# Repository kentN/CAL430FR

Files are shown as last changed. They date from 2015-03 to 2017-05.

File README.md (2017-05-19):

# CAL.430FR #

MSP430FR5949 TimeKeeping Module with ADXL362 & Sharp MemoryLCD



----------

## Features ##

- MSP430FR5949 FRAM MCU (FRAM 64kB, SRAM 2kB, LFXT only)
- Sharp Memory LCD (128x128pixcel or 96x96pixcel)
- 5 button
- Low Power Accelerometer ADXL362
- 32.768kHz External Crystal
- CR2032 Coin Cell battery (Diode OR option)
- External Connector(DF12-20p) includes MSP430 prog pin, UART(x2ch), SPI(x1), GPIO(x9)

----------
## Applications ##

- DIY WristWatch
- Embedded Display&TimeKeeping module
- Motion Data Logger

----------

## Project Environment ##

- KiCad (4.0.1)
- MSP430FR5969 LaunchPad
- Energia IDE
- CCSv6

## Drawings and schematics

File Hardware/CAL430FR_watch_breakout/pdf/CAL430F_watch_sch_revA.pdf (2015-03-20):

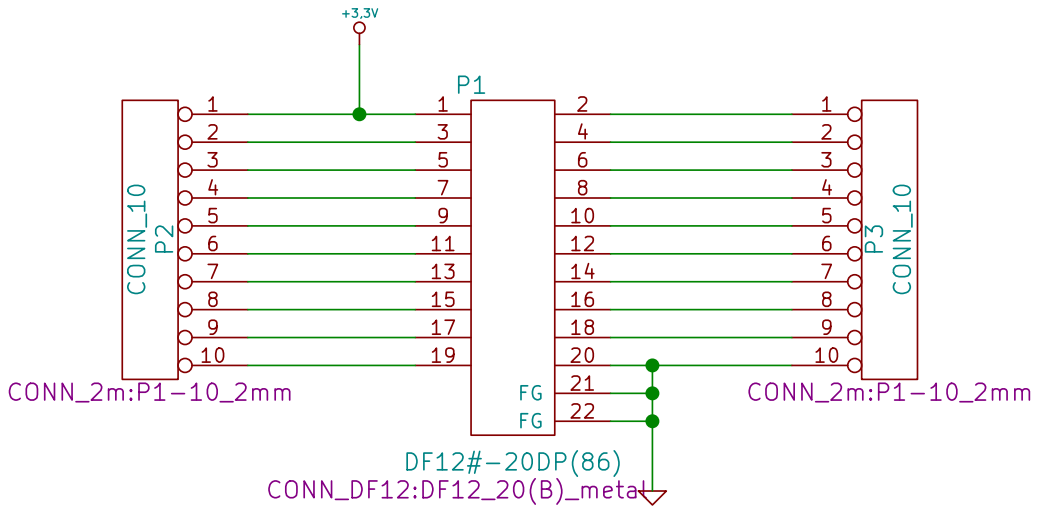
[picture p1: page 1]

File: CAL430F_PROG.sch Sheet: / Kent Nakazawa (kent_n@outlook.com)

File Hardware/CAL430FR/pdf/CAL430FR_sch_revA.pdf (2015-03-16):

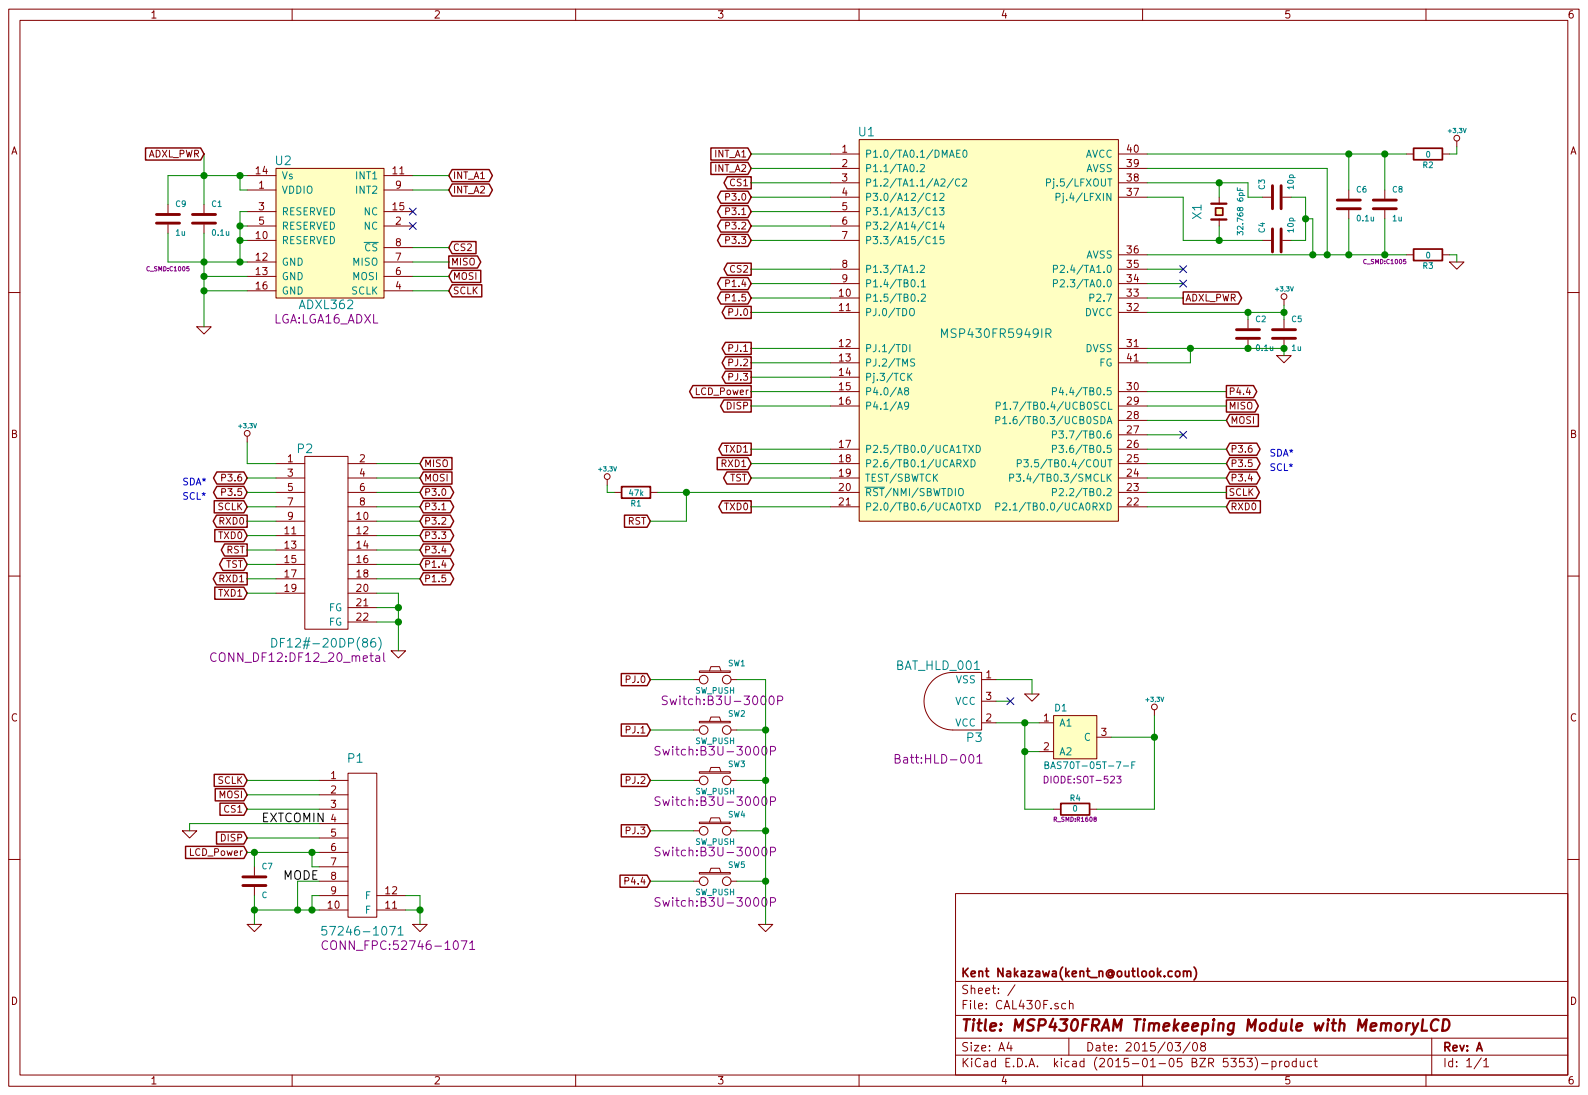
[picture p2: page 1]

Id: 1/1 Title: MSP430FRAM Timekeeping Module with MemoryLCD

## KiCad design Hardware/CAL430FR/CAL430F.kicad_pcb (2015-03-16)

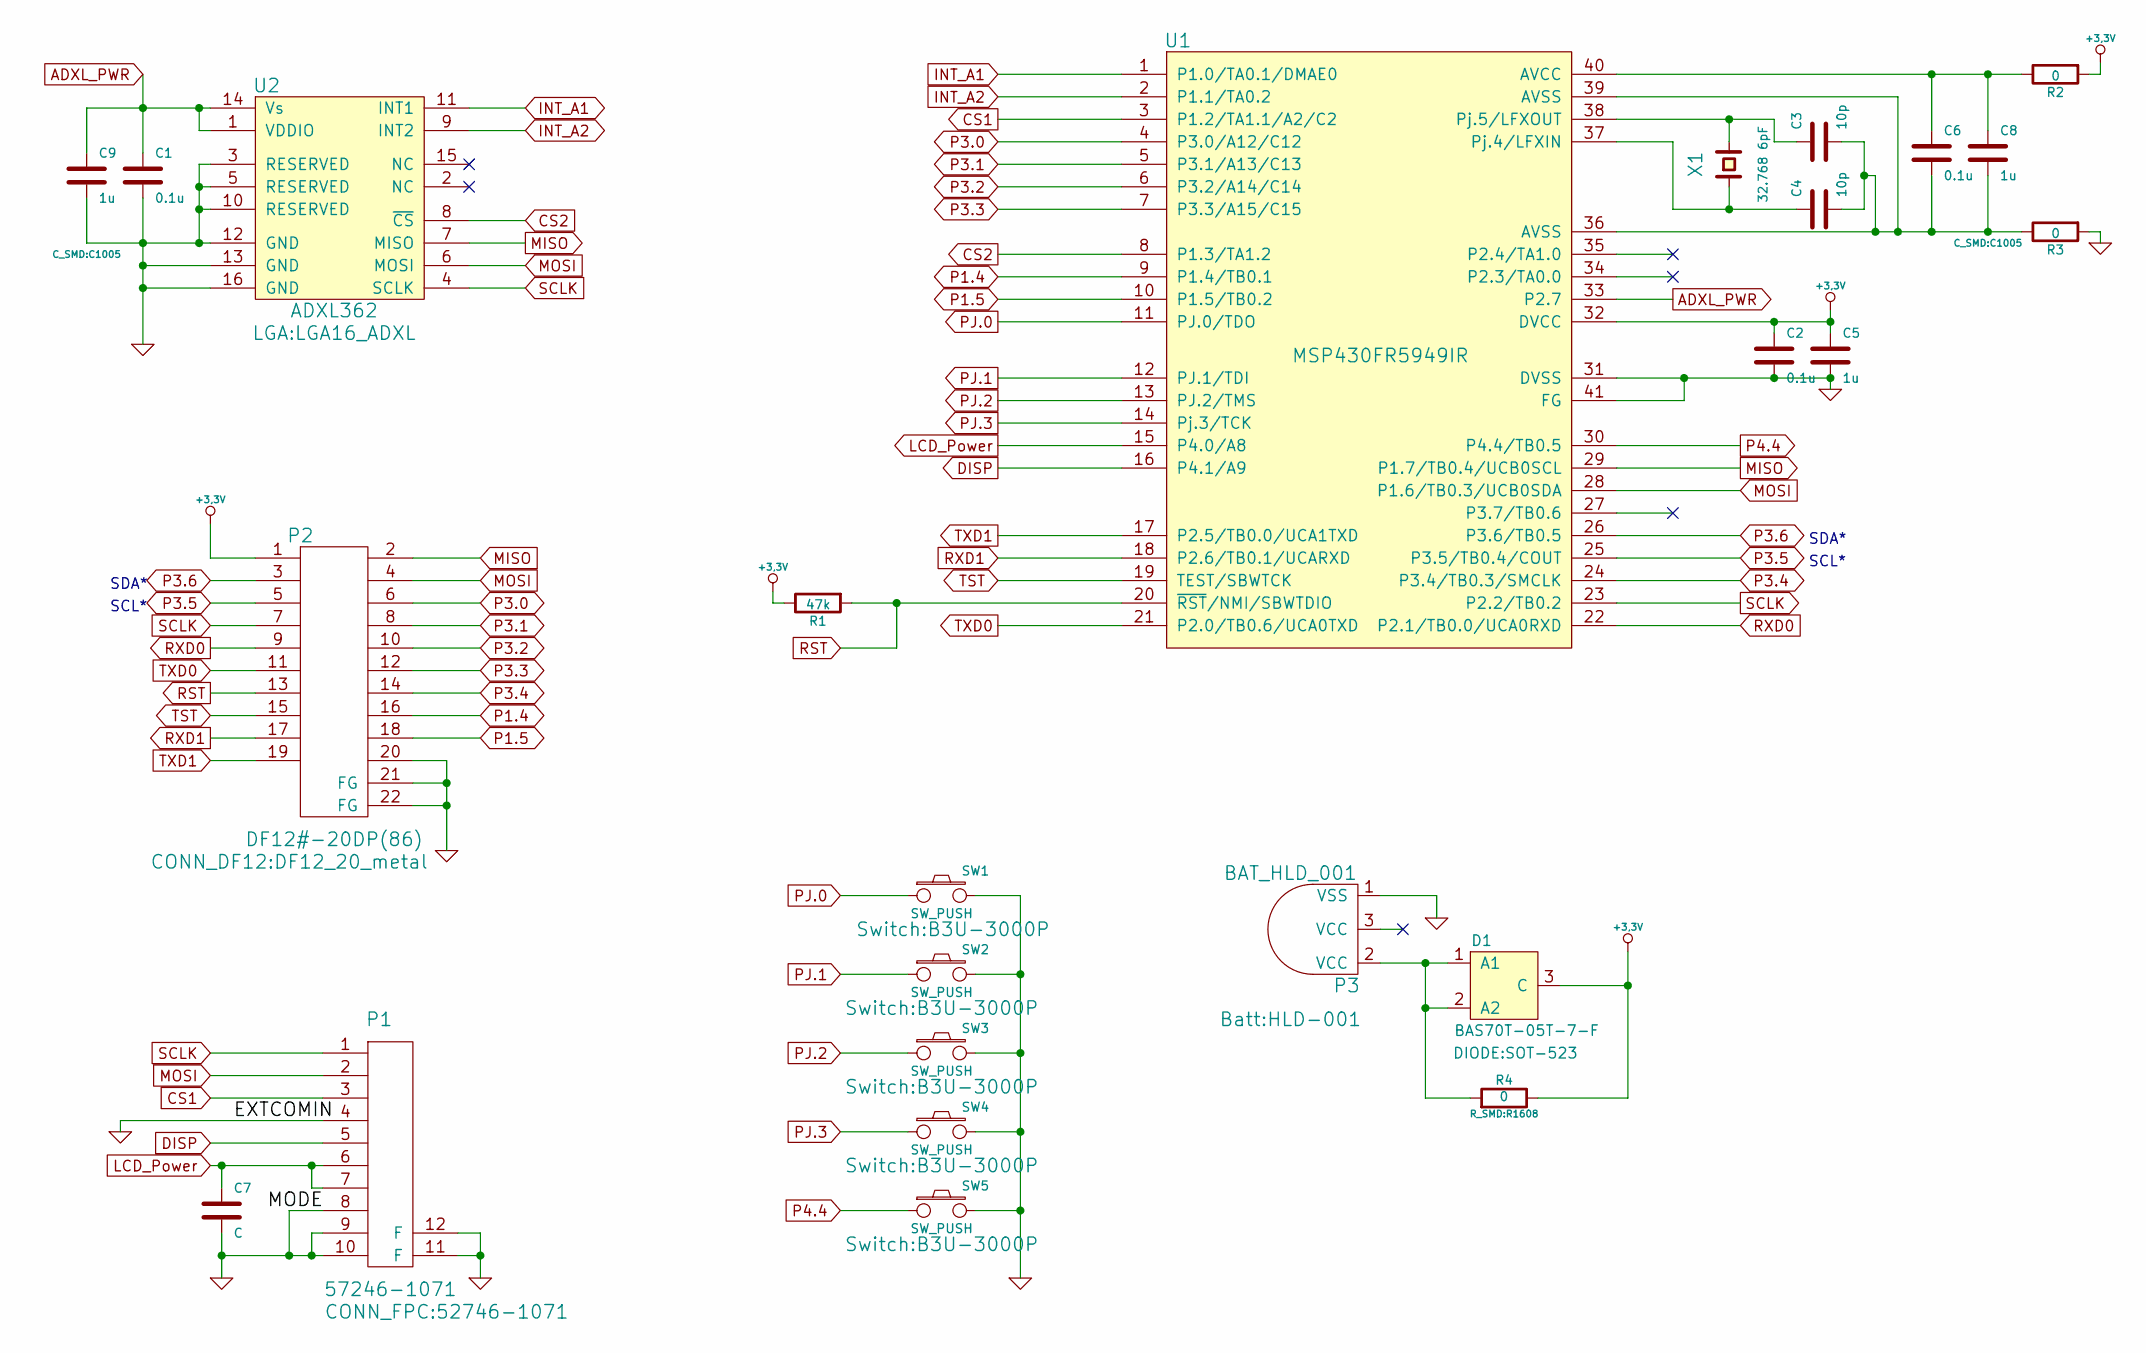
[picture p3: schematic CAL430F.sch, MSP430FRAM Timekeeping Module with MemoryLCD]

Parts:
C1, C2, C6: 0.1u; C1005
C3, C4: 10p; C1005
C5, C8, C9: 1u; C1005
C7: C; C1005
D1: BAS70T-05T-7-F; SOT-523
P1: 57246-1071; 52746-1071
P2: DF12#-20DP(86); DF12_20_metal
P3: BAT_HLD_001; HLD-001
R1: 47k; R1005
R2, R3: 0; R1005
R4: 0; R1608
SW1, SW2, SW3, SW4, SW5: SW_PUSH; B3U-3000P
U1: MSP430FR5949IR; QFN40
U2: ADXL362; LGA16_ADXL
X1: 32.768 6pF; CRYSTAL_2012

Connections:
+3.3V: C2.1, C5.1, D1.3 (C), P2.1, R1.2, R2.1, R4.2, U1.32 (DVCC)
ADXL_PWR: C1.1, C9.1, U1.33 (P2.7), U2.1 (VDDIO), U2.14 (Vs)
CS1: P1.3, U1.3 (P1.2/TA1.1/A2/C2)
CS2: U1.8 (P1.3/TA1.2), U2.8 (~CS)
DISP: P1.5, U1.16 (P4.1/A9)
GND: C1.2, C2.2, C5.2, C7.2, C9.2, P1.4, P1.8, P1.9, P1.10, P1.11 (F), P1.12 (F), P2.20, P2.21 (FG), P2.22 (FG), P3.1 (VSS), R3.1, SW1.2, SW2.2, SW3.2, SW4.2, SW5.2, U1.31 (DVSS), U1.41 (FG), U2.3 (RESERVED), U2.5 (RESERVED), U2.10 (RESERVED), U2.12 (GND), U2.13 (GND), U2.16 (GND)
INT_A1: U1.1 (P1.0/TA0.1/DMAE0), U2.11 (INT1)
INT_A2: U1.2 (P1.1/TA0.2), U2.9 (INT2)
LCD_Power: C7.1, P1.6, P1.7, U1.15 (P4.0/A8)
MISO: P2.2, U1.29 (P1.7/TB0.4/UCB0SCL), U2.7 (MISO)
MOSI: P1.2, P2.4, U1.28 (P1.6/TB0.3/UCB0SDA), U2.6 (MOSI)
unnamed: C3.1, U1.38 (Pj.5/LFXOUT), X1.2
unnamed: C3.2, C4.2, C6.2, C8.2, R3.2, U1.36 (AVSS), U1.39 (AVSS)
unnamed: C4.1, U1.37 (Pj.4/LFXIN), X1.1
unnamed: C6.1, C8.1, R2.2, U1.40 (AVCC)
unnamed: D1.1 (A1), D1.2 (A2), P3.2 (VCC), R4.1
P1.4: P2.16, U1.9 (P1.4/TB0.1)
P1.5: P2.18, U1.10 (P1.5/TB0.2)
P3.0: P2.6, U1.4 (P3.0/A12/C12)
P3.1: P2.8, U1.5 (P3.1/A13/C13)
P3.2: P2.10, U1.6 (P3.2/A14/C14)
P3.3: P2.12, U1.7 (P3.3/A15/C15)
P3.4: P2.14, U1.24 (P3.4/TB0.3/SMCLK)
P3.5: P2.5, U1.25 (P3.5/TB0.4/COUT)
P3.6: P2.3, U1.26 (P3.6/TB0.5)
P4.4: SW5.1, U1.30 (P4.4/TB0.5)
PJ.0: SW1.1, U1.11 (PJ.0/TDO)
PJ.1: SW2.1, U1.12 (PJ.1/TDI)
PJ.2: SW3.1, U1.13 (PJ.2/TMS)
PJ.3: SW4.1, U1.14 (Pj.3/TCK)
RST: P2.13, R1.1, U1.20 (~RST~/NMI/SBWTDIO)
RXD0: P2.9, U1.22 (P2.1/TB0.0/UCA0RXD)
RXD1: P2.17, U1.18 (P2.6/TB0.1/UCARXD)
SCLK: P1.1, P2.7, U1.23 (P2.2/TB0.2), U2.4 (SCLK)
TST: P2.15, U1.19 (TEST/SBWTCK)
TXD0: P2.11, U1.21 (P2.0/TB0.6/UCA0TXD)
TXD1: P2.19, U1.17 (P2.5/TB0.0/UCA1TXD)

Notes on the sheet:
SDA*
SCL*

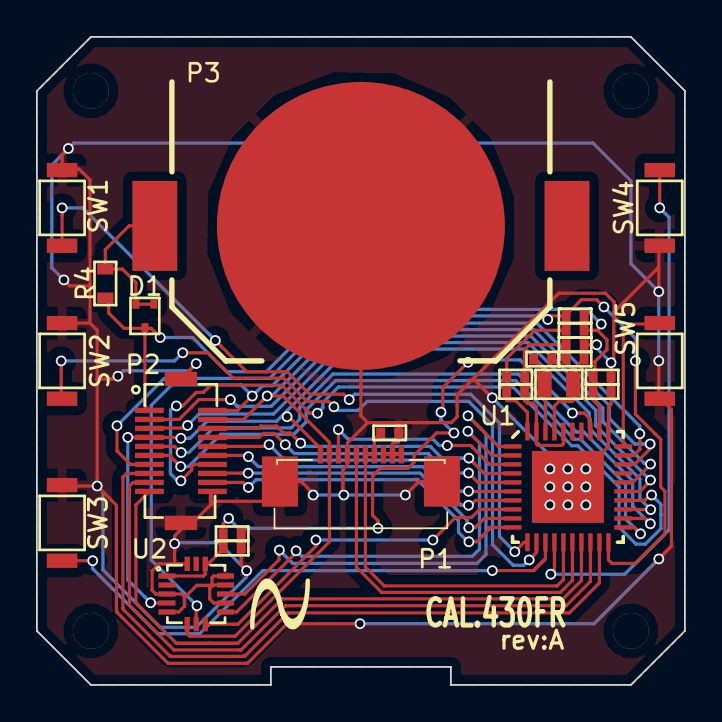
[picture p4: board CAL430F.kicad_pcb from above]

Board: 2 copper layers, 36.0 x 36.0 mm, 29 parts (0 on the bottom side), 37 nets.

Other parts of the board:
Drill_M2, Drill_M2#2, Drill_M2#3, Drill_M2#4: VAL**; Drill_M2

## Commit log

2015-03-11 revision: A
    KiCad Archive files
    [.sch.sch, CAL430F.kicad_pcb, CAL430F.sch]
2015-03-11 rename schematic
2015-03-16 Clean kicad files
    [.sch.sch, CAL430F.kicad_pcb, CAL430F.sch]
2015-03-20 add watch breakout PCB files
    CAL430FR_watch_breakout_revA
    [CAL430F_watch.kicad_pcb, CAL430F_watch.sch]
